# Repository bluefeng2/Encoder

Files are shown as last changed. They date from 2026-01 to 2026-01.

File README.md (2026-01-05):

# Magnetic Encoder

## Overview
This project is a custom magnetic encoder designed to act as a drop-in replacement for the CTRE CANCoder.  
The goal was to swap the encoder in without redesigning mounts or assemblies.

The encoder uses the AS5048A magnetic encoder IC and outputs PWM, making it easy to integrate with the roboRIO.

---

## Component Selection
- AS5048A magnetic encoder IC
  - High-resolution rotation sensing
  - Built-in PWM output
- PWM was chosen over SPI or CAN:
  - roboRIO has limited SPI ports
  - Long SPI wires are unreliable
  - CAN has complex circurity
  - CAN requires custom low-level code (Maybe next time)

---

## Case CAD
The bottom case was designed to closely match the CANCoder’s geometry.

- Two mounting holes match the CANCoder
- PCB is retained using snap-in clips

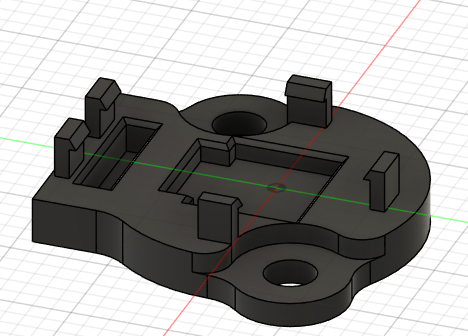
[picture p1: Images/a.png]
Case CAD


---

## PCB Schematic

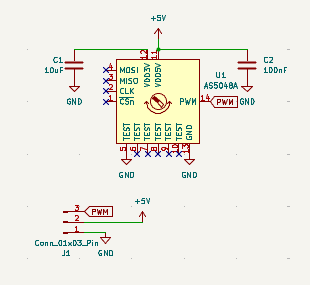
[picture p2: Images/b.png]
PCB Schematic


---

## PCB Layout

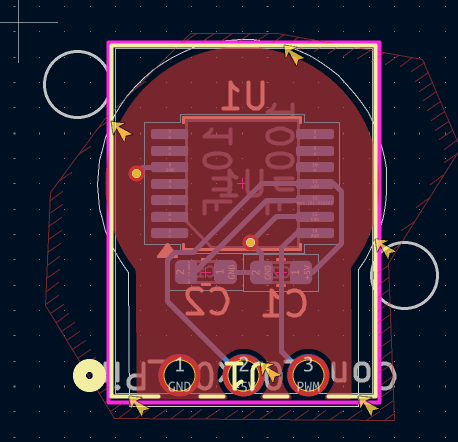
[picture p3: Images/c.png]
PCB Layout


---

## Case + PCB Assembly

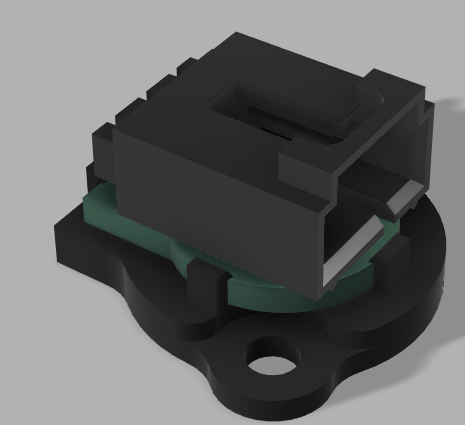
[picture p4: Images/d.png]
Case and PCB Assembly


---

## BOM

| Item | Quantity | Unit Cost (CAD) | Total Cost (CAD) | Supplier | Link |
|---|---|---|---|---|---|
| Molex SL Connector (70553-0002) | 3 | 1.34 | 13.58 | Digi-Key | https://www.digikey.ca/en/products/detail/molex/0705530002/114955 |
| Custom PCB | 1 | 23.24 | 23.24 | JLCPCB | — |
| Diametric Cylinder Magnet (5 mm × 12 mm) | 8 | 1.25 | 22.76 | Magnet Montreal | https://magnetmontreal.com/neodymium-cylinder-magnets/cylinder-diametric-magnet-5mm-wide-x-12mm-high-0.2-x-0.47.html |
| Total:| — | — | — | 59.58 CAD | 43.16  USD |

*Total cost includes shipping

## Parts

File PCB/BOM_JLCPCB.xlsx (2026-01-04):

Comment | Designator | Footprint
100nF | C2 | C_0603_1608Metric
AS5048A | U1 | TSSOP-14_4.4x5mm_P0.65mm
10uF | C1 | C_0603_1608Metric

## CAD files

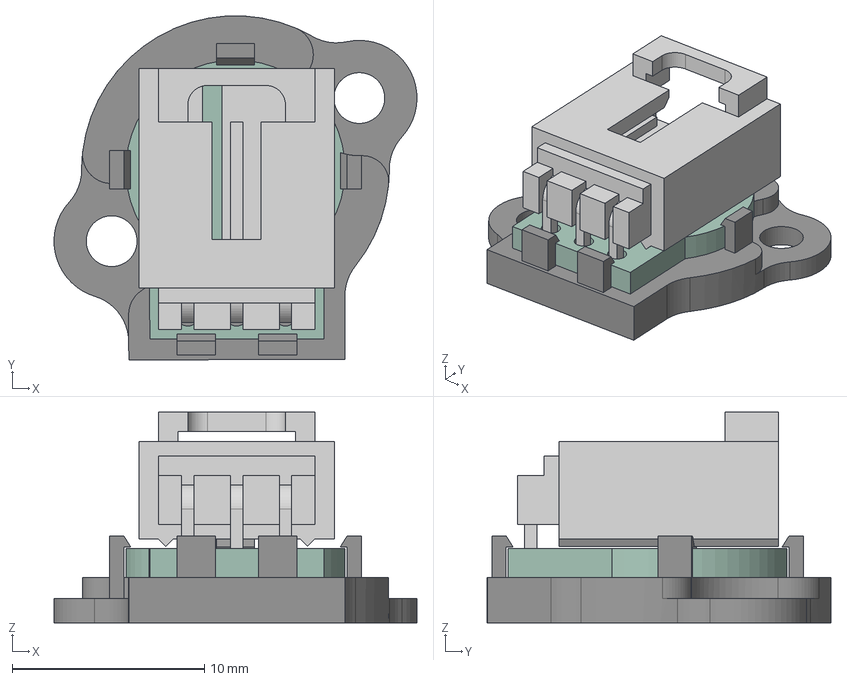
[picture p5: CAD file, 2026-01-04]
CAD/Case.step
18.9 x 17.9 x 11.0 mm
C_0603_1608Metric x 2
TSSOP-14_4.4x5mm_P0.65mm
encoder_PCB
Case Bottom

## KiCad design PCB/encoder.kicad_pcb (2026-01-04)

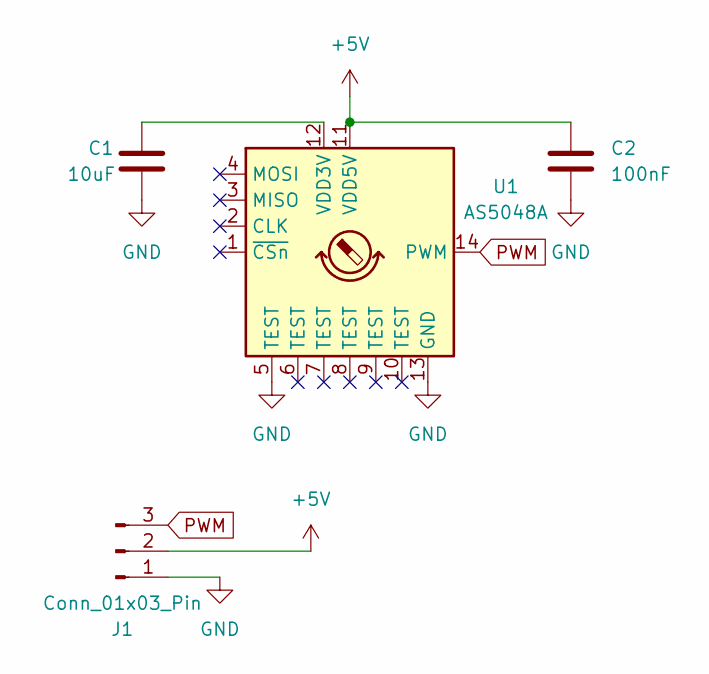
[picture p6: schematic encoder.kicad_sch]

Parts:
C1: 10uF; C_0603_1608Metric
C2: 100nF; C_0603_1608Metric
J1: Conn_01x03_Pin; CONN_70553-xxxx_03_MOL
U1: AS5048A; TSSOP-14_4.4x5mm_P0.65mm

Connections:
+5V: C2.1, J1.2, U1.11 (VDD5V)
GND: C1.1, C2.2, J1.1, U1.5 (TEST), U1.13 (GND)
unnamed: C1.2, U1.12 (VDD3V)
PWM: J1.3, U1.14 (PWM)

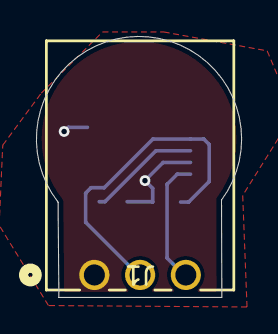
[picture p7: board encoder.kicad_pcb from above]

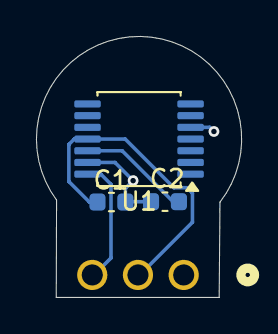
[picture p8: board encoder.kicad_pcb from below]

Board: 2 copper layers, 11.4 x 14.5 mm, 4 parts (3 on the bottom side), 4 nets.

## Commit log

2026-01-04 Update total costs and magnet price in README
2026-01-05 Update BOM.csv with new quantities and totals
    [BOM.csv]
